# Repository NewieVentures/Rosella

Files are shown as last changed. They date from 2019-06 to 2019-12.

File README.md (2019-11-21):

# Rosella (code name Project Faraday)
### By NewieVentures

Remote control of LED strip lights via DMX over cellular.

## Hardware
### Artifacts
* FP1 - Motherboard
* FP2 - DMX expansion module
* FA1 - Assembled unit
* FA2 - Demonstration panel

## LED patterns
To update the pattern of an active device, the device ID and a valid access token is required:

`curl -v "https://api.particle.io/v1/devices/<DEVICE_ID>/<function>" -d access_token=<TOKEN> -d arg=<ARG>`

eg to set a green strobe at 1Hz:

`curl -v "https://api.particle.io/v1/devices/<your device ID here>/strobe" -d access_token=<your access token here> -d arg="1000,#00FF00"`

### Blink
Flash LEDs on and off. Duty cycle controls amount of time on vs off.
#### Arguments
`"<period (ms)>,<duty cycle (0-100)>,<colour-on>,<colour-off>"`

eg blink red 1s:

`POST /v1/devices/:deviceId/blink { "arg": "1000,50,#FF0000,#000000" }`

### Colour
Fixed colour on all leds
#### Arguments
`"<colour>"`

Eg all LEDS blue:

`POST /v1/devices/:deviceId/colour { "arg": "#0000FF" }`

### Gradient
Linear colour gradient
#### Arguments
`"<start-colour>,<end-colour>"`

eg gradient on all LEDS from red to green:

`POST /v1/devices/:deviceId/gradient { "arg": "#FF0000,#00FF00" }`

### Progress
Progress bar
#### Arguments
* Initial value: 0 - (# leds – 1)
* Final value: 1 - #leds
* Direction: 0 = first LED to last, 1 = last LED to first

`"<initial value>,<final value><increment (# leds)>,<increment delay (ms)>,<reset delay(ms)>,<direction>,<colour-on>,<colour-off>"`

eg Progress bar from 0 to 100 leds with 1s between increments, 5s pause at the final value
before repeating and starting from the first LED to the last, incrementing by 1 LED with
RED being on and black being off:

```
POST /v1/devices/:deviceId/progress
{ "arg": "0,100,1,1000,5000,0,#FF0000,#000000" }
```

### Snake
Block of LEDS moving along the strip.
#### Arguments
* Direction: 0 = first LED to last, 1 = last LED to first
`"<period (ms)>,<direction>,<length (# leds)>,<colour-on>,<colour-off>"`

eg Green block of 3 LEDS moving from first LED to last every 5s on a black background:

`POST /v1/devices/:deviceId/snake { "arg": "5000,0,3,#00FF00,#000000" }`

### Strobe
Flash LEDs
#### Arguments
`"<period (ms)>,<colour>"`

eg Blue flash at 1Hz

`POST /v1/devices/:deviceId/strobe { "arg": "1000,#0000FF" }`

## Firmware
The firmware is compiled using the particle cloud development tools (internet connection required).

### Setup
Install the particle CLI, see docs at
https://docs.particle.io/tutorials/developer-tools/cli/

### Compiling
To compile using the particle CLI:
`particle compile electron app --saveTo electron.bin`

### Flashing
To flash a binary to the module over USB, put it into programming mode then:
`particle flash --usb electron.bin`

### Unit tests
```
cd src
make tests && ./tests
```

### Structure
The firmware runs on a Particle Electron board, using their Device OS.  The major firmware modules are:
* cloudFunctions - functions registered with Particle's Device OS on boot and called via their cloud interface.
* LedStripDriver - generates colour values for each LED based on the pattern and settings.  The cloud functions change the pattern settings, while a timer in the RTOS calls the onTimerFired() method to process the new values.
* dmx - uses Serial1 to send the DMX packets (requires some low level override of the baud rate to send the break and mark-after-break at the start of the packet) and sends the NULL start code in each packet.

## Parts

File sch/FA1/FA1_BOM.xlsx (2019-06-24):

Refs | Description | Manufacturer | Order Number | Part Number | Supplier | Quantity | Price | Subtotal | Notes
D1 | LED PANEL INDICATOR RED 1.8V IP67 | E-Switch | EG5379-ND | PVL16FLS11 | Digikey | 1 | $16.49 | $16.49
D2 | LED PANEL INDICATOR BLUE 2.8V IP67 | E-Switch | EG5381-ND | PVL16FLS41 | Digikey | 1 | $16.49 | $16.49
J1 | PWR ENT RCPT IEC320-C14 PANEL QC | Qualtek | Q212-ND | 703W-00/04 | Digikey | 1 | $1.19 | $1.19
J2 | CONN SMA JACK STR 50 OHM SOLDER | Amphenol | ACX1183-ND | 132105 | Digikey | 1 | $11.94 | $11.94
J3 | TERM BLK HEADER 4POS GREEN | Phoenix Contact | 277-6689-ND | 1899155 | Digikey | 1 | $6.49 | $6.49
U1 | FP1 sub-assembly |  |  |  |  | 1 |  | $0.00
U2 | AC/DC CONVERTER 5V 5W | Mean Well | 1866-5411-ND | PS-05-5 | Digikey | 1 | $9.64 | $9.64 | Not required if using PSU on FP1
 | IP65 Sealed ABS enclosure 222x146x55mm | Multicomp | HB-6130 | MC001120 | Jaycar | 1 | $24.95 | $24.95
 | CONN HOUSING VH 2POS 3.96MM WHT | JST | 455-1183-ND | VHR-2N | Digikey | 3 | $0.17 | $0.51
 | CONN HOUSING VH 3POS 3.96MM WHT | JST | 455-1184-ND | VHR-3N | Digikey | 1 | $0.20 | $0.20
 | CONN TERM CRIMP VH/NV 18-22AWG | JST | 455-1133-1-ND | SVH-21T-P1.1 | Digikey | 9 | $0.16 | $1.44
 | Wire |  |  |  |  |  |  |  | Used for LEDs, IEC, SMA and DMX
 | ANT LTE BLADE SWIVEL DIPOLE SMA | Linx Technologies | ANT-LTE-WS-SMA-ND | ANT-LTE-WS-SMA | Digikey | 1 | $13.62 | $13.62
 | Screw M3 x 6mm Pan SS |  |  |  |  | 4 |  | $0.00
 | Washer Flat M3 SS |  |  |  |  | 4 |  | $0.00
 | Screw M3 x 10mm Pan SS |  |  |  |  | 4 |  | $0.00
 | Nut M3 SS |  |  |  |  | 4 |  | $0.00
 | Washer Spring M3 SS |  |  |  |  | 4 |  | $0.00
 | TERM BLOCK PLUG 4POS STR 5.08MM | Phoenix Contact | 277-5925-ND | 1780002 | Digikey | 1 | $8.88 | $8.88
 | CBL ASSY U.FL PLUG to cable 100mm | Hirose Electric Co | H125220-ND | U.FL-LP-066J1-A-(100) | Digikey | 1 | $8.02 | $8.02 | Can use cable from kit (de-solder from PCB antenna)
 |  |  |  |  |  |  | Total | $86.88

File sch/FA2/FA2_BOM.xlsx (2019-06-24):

Refs | Description | Manufacturer | Order Number | Part Number | Supplier | Quantity | Price | Subtotal | Notes
U1 | DMX-512 Decoder SPI output 5-24VDC | LTECH | LT-DMX-1809 | LT-DMX-1809 | Agoeu LED Express Store | 1 | $34.11 | $34.11
U2 | FA1 | Newie Ventures |  |  |  | 1 |  | $0.00
U3 | AC adapter 110-240VAC to 5V 3A DC |  | MP3480 |  | Jaycar | 1 | $24.95 | $24.95
U4, U5 | 5M RGB LED Strip - WS2812 60 Per Meter - White Strip - Weatherproof |  | CE04854 |  | Core Electronics | 0.4 | $69.00 | $27.60
 | Melamine panel |  |  |  |  | 1
 | Power board |  | MS4040 |  | Jaycar | 1 | $5.00 | $5.00
 | IEC cable |  | PS4106 |  |  | 1 | $8.95 | $8.95
 | Screws, wood
 |  |  |  |  |  |  | Total | $91.66

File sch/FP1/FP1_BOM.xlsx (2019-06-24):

Refs | Description | Manufacturer | Order Number | Part Number | Supplier | Quantity | Price | Subtotal | Notes
C1, C5 | CAP CER 1nF 450V C0G 0805 | TDK | 445-15536-1-ND | CGA4C4C0G2W102J060AA | Digikey | 2 | $0.51 | $1.02 | Optional if external 5VDC used
C2 | CAP CER 1UF 50V X7R 0805 | Samsung Electro-mechanics | 1276-6470-1-ND | CL21B105KBFNNNG | Digikey | 1 | $0.20 | $0.20
C3 | CAP ALUM 470UF 20% 10V RADIAL | Kemet | 399-6589-ND | ESH477M010AE3AA | Digikey | 1 | $0.36 | $0.36
C4 | CAP CER 0.1uF 630V X7R 1210 | Kemet | 399-13490-1-ND | C1210C104KBRAC7800 | Digikey | 1 | $0.69 | $0.69
C6 | CAP CER 10UF 10V 10% X5R 0805 | Samsung Electro-mechanics | 1276-2402-1-ND | CL21A106KPCLQNC | Digikey | 1 | $0.30 | $0.30
C7 | CAP CER 0.1UF 50V X7R 0805 | Murata | 490-8049-1-ND | GCM21BR71H104KA37K | Digikey | 1 | $0.33 | $0.33
D1 | TVS DIODE 7Vs 12Vc 600W | Littelfuse | SMBJ7.0ALFCT-ND | SMBJ7.0A | Digikey | 1 | $0.61 | $0.61
F1 | FUSE BOARD MNT 2A 250VAC 125VDC | Schurter | 486-1250-ND | 3403.0169.11 | Digikey | 1 | $0.93 | $0.93 | Optional if external 5VDC used
J1 | CONN HEADER VH TOP 3POS 3.96MM | JST | 455-1640-ND | B3P-VH(LF)(SN) | Digikey | 1 | $0.35 | $0.35 | Optional if external 5VDC used
J2, J4 | CONN HEADER FEMALE 9POS .1\" GOLD | Sullins Connector Solutions | S7042-ND | PPPC091LFBN-RC | Digikey | 4 | $0.97 | $3.88
J3, J5, J6 | CONN HEADER VH TOP 2POS 3.96MM | JST | 455-1639-ND | B2P-VH(LF)(SN) | Digikey | 3 | $0.27 | $0.81
L1 | IND 4.7uH 2A 72 mOHM SMD | Taiyo Yuden | 587-2407-1-ND | NRS5020T4R7MMGJ | Digikey | 1 | $0.49 | $0.49 | Optional if external 5VDC used
L2 | Common Mode Choke 10mH 2A 2 lines through hole | Schaffner | 817-2142-ND | RN143-2-02-10M | Digikey | 1 | $4.18 | $4.18 | Optional if external 5VDC used
PS1 | AC-DC 100-240VAC to 5VDC 2A and 12V 400mA | Mornsun | LHE15-20D0512-04 | LHE15-20D0512-04 | Mornsun | 1 |  | $0.00 | Optional if external 5VDC used
R1, R2 | RES SMD 4.7K OHM 5% 1/8W 0805 | Yageo | 311-4.7KARCT-ND | RC0805JR-074K7L | Digikey | 2 | $0.14 | $0.28
R3, R4 | RES SMD 220 OHM 5% 0.4W 0805 | Rohm | RHM220KCT-ND | ESR10EZPJ221 | Digikey | 2 | $0.14 | $0.28
RV1 | VARISTOR 470V 4.5KA DISC 14MM | Bourns | MOV-14D471K-ND | MOV-14D471K | Digikey | 1 | $0.68 | $0.68 | Optional if external 5VDC used
U1 | Particle Electron 3G Kit | Particle | CE04423 | Electron | Core Electronics | 1 | $135.00 | $135.00
J2, J4 | CONN HEADER FEMALE 4POS .1\" GOLD | Sullins Connector Solutions | S7037-ND | PPPC041LFBN-RC | Digikey | 4 | $0.68 | $2.72
 |  |  |  |  |  |  | Total | $153.11

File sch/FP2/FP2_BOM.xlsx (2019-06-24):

Refs | Description | Manufacturer | Order Number | Part Number | Supplier | Quantity | Price | Subtotal | Notes
C1 | CAP CER 10UF 10V X5R 0805 | Samsung Electro-mechanics | 1276-2402-1-ND | CL21A106KPCLQNC | Digikey | 1 | $0.30 | $0.30
C2 | CAP CER 0.1UF 50V X7R 0805 | Murata | 490-8049-1-ND | GCM21BR71H104KA37K | Digikey | 1 | $0.33 | $0.33
D1, D2 | TVS DIODE 43V 69.4V DO214AA | Littelfuse | SMBJ43CALFCT-ND | SMBJ43CA | Digikey | 2 | $0.84 | $1.68
J1 | TERMINAL BLOCK 5.08MM 3POS PCB | On Shore Technology | ED2903-ND | OSTYC032150 | Digikey | 1 | $1.55 | $1.55
J2 | CONN HEADER MALE 18POS .1\" | Amphenol FCI | 609-5513-ND | 68001-418HLF | Digikey | 1 | $0.87 | $0.87
R1, R5, R6 | RES SMD 10K OHM 1% 1/8W 0805 | Yageo | 311-10.0KCRCT-ND | RC0805FR-0710KL | Digikey | 3 | $0.14 | $0.42
R2, R4 | RES SMD 10 OHM 5% 0.4W 0805 | Rohm | RHM10KCT-ND | ESR10EZPJ100 | Digikey | 2 | $0.14 | $0.28
R3 | RES SMD 120 OHM 5% 0.4W 0805 | Rohm | RHM120KCT-ND | ESR10EZPJ121 | Digikey | 1 | $0.14 | $0.14
U1 | IC TXRX RS485 HALF DUPLEX 8SOIC | MaxLinear | 1016-1827-6-ND | SP485EEN-L/TR | Digikey | 1 | $1.46 | $1.46
 |  |  |  |  |  |  | Total | $7.03

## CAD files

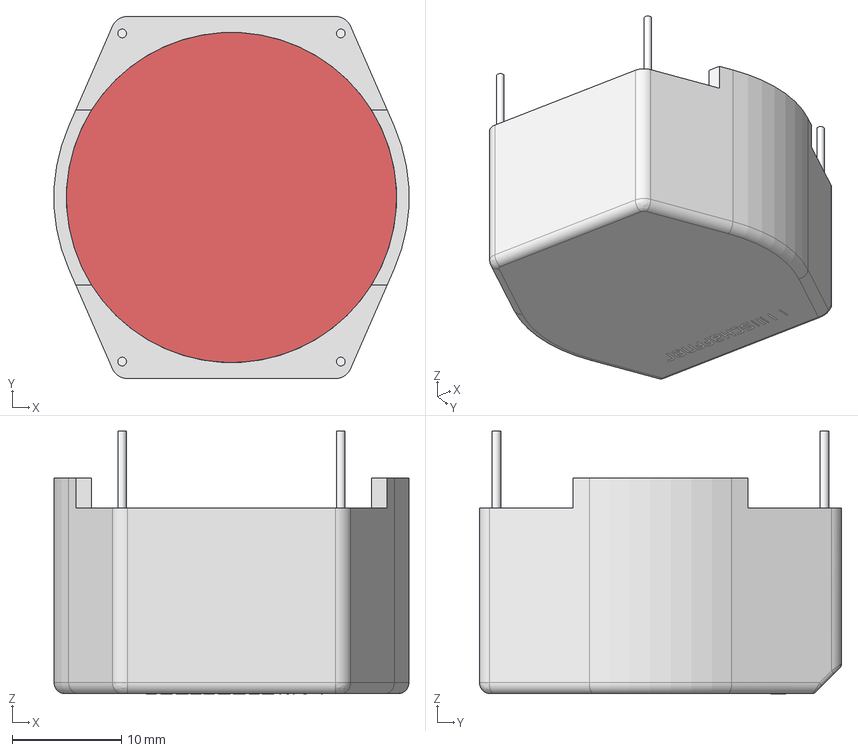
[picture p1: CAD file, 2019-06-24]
sch/3D files/RN143-x-02.stp
32.4 x 33.1 x 24.0 mm

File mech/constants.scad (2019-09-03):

$fn=400; // How many sections to use for circles

/************************************************************************
* Seeeduino board
************************************************************************/
SEEEDUINO_BRD_W = 53.4;
SEEEDUINO_BRD_L = 68.6;
SEEEDUINO_BRD_H = 1.2;
SEEEDUINO_HOLE_D = 3.2;

HDR_W = 2.5;
HDR_H = 9.1;
HDR_L_TL = 20.9;
HDR_L_BL = 26.0;
HDR_L_TR = 15.8;
HDR_L_BR = 20.9;

HDR_OFS_TOP = 2.6;

HOLE_OFS_X = SEEEDUINO_HOLE_D/2 + 1;
BOT_HOLE_OFS_Y = SEEEDUINO_HOLE_D/2 + 1;
MID_OUT_HOLE_OFS_Y = 16.9 - SEEEDUINO_HOLE_D/2;

MID_IN_HOLE_OFS_X = 6.6 + SEEEDUINO_HOLE_D/2;
MID_IN_HOLE_OFS_Y = 6.6 + SEEEDUINO_HOLE_D/2;

TOP_RIGHT_HOLE_OFS_X = SEEEDUINO_BRD_W - 6 - SEEEDUINO_HOLE_D/2;
TOP_LEFT_HOLE_OFS_X = SEEEDUINO_BRD_W - 37.2 - SEEEDUINO_HOLE_D/2;
TOP_HOLE_OFS_Y = SEEEDUINO_BRD_L - 1 - SEEEDUINO_HOLE_D/2;

BRD_HOLE_OFS_X_BL = SEEEDUINO_HOLE_D/2 + 1;
BRD_HOLE_OFS_X_BR = SEEEDUINO_BRD_W - BRD_HOLE_OFS_X_BL;
BRD_HOLE_OFS_X_TL = SEEEDUINO_BRD_W - 37.2 + SEEEDUINO_HOLE_D/2;
BRD_HOLE_OFS_X_TR = SEEEDUINO_BRD_W - 6 - SEEEDUINO_HOLE_D/2;

BRD_HOLE_OFS_Y_BL = SEEEDUINO_HOLE_D/2 + 1;
BRD_HOLE_OFS_Y_BR = BRD_HOLE_OFS_Y_BL;
BRD_HOLE_OFS_Y_TL = SEEEDUINO_BRD_L - 1 - SEEEDUINO_HOLE_D/2;
BRD_HOLE_OFS_Y_TR = BRD_HOLE_OFS_Y_TL;

BRD_MOUNT_HOLE_D = 3.0;

/************************************************************************
* Mount plate
************************************************************************/
MOUNT_PLATE_D = 71;
MOUNT_PLATE_H = 2.9;
MOUNT_HOLE_D = 4.2;
BRD_POST_D = 6.5;
BRD_POST_LEN = 10;
BRD_POST_ANG = 60;
BRD_POST_H = 5;
BRD_SCREW_POST_H = 3;
SCREW_HEAD_D = 7.6;
SCREW_HEAD_H = 2.7;

MNT_HOLE_TO_HOLE = 54.2; // center to center
MNT_HOLE_EDGE_OFS = 2.6; // offset from disc edge
MNT_HOLE_ANGLE = 60;

STR_REL_D = 6;
STR_REL_H = 5;
STR_REL_HOLE_D = 3;

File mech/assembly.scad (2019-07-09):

include <constants.scad>
use <button_mount_plate.scad>
use <seeeduino_lorawan_shield.scad>

mount_plate();

translate([-SEEEDUINO_BRD_W/2, -SEEEDUINO_BRD_L/2, MOUNT_PLATE_H + BRD_POST_H]) seeeduino_lorawan_shield();

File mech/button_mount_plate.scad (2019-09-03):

include <constants.scad>

MNT_TOP_Y = MOUNT_PLATE_D/2 - MNT_HOLE_EDGE_OFS - MOUNT_HOLE_D/2;

TERM_BLOCK_SIZE = 36;

SHOW_TERM_BLOCK = false;

module mount_hole() {
    translate([0, 0, MOUNT_PLATE_H - SCREW_HEAD_H + 0.001]) 
      cylinder(d1=MOUNT_HOLE_D, d2=SCREW_HEAD_D, h=SCREW_HEAD_H);
    cylinder(d=MOUNT_HOLE_D, h=MOUNT_PLATE_H*3, center=true);
}

module mounting_post(l, x_ofs, y_ofs, angle) {
    translate([-(SEEEDUINO_BRD_W/2 - x_ofs), 
                   -(SEEEDUINO_BRD_L/2 - y_ofs), 
                   MOUNT_PLATE_H+0.001]) {
      difference() {
        union() {
            hull() {
              cylinder(d=BRD_POST_D, h=BRD_POST_H);
              translate([l*cos(angle), l*sin(angle)]) cylinder(d=BRD_POST_D, h=BRD_POST_H);
            }
        translate([0, 0, BRD_POST_H]) cylinder(d=BRD_POST_D, h=BRD_SCREW_POST_H);
        }
        cylinder(d=BRD_MOUNT_HOLE_D, 3*(BRD_POST_H + BRD_SCREW_POST_H), center=true);
      }
        
        
    }
}

module mount_plate() {
    difference() {
        color("grey") cylinder(d=MOUNT_PLATE_D, h=MOUNT_PLATE_H);
        
        // mount hole top
        translate([0, MNT_TOP_Y, 0]) mount_hole();
        
        // mount hole left
        translate([-(MNT_HOLE_TO_HOLE*sin(MNT_HOLE_ANGLE/2)), MNT_TOP_Y - MNT_HOLE_TO_HOLE*cos(MNT_HOLE_ANGLE/2), 0]) mount_hole();
        
        // mount hole right
        translate([(MNT_HOLE_TO_HOLE*sin(MNT_HOLE_ANGLE/2)), MNT_TOP_Y - MNT_HOLE_TO_HOLE*cos(MNT_HOLE_ANGLE/2), 0]) mount_hole();
    }
    
    // bottom left
    mounting_post(BRD_POST_LEN, BRD_HOLE_OFS_X_BL, BRD_HOLE_OFS_Y_BL, angle=52.5);

    // bottom right
    mounting_post(0.88*BRD_POST_LEN, BRD_HOLE_OFS_X_BR, BRD_HOLE_OFS_Y_BR, angle=80);

    // top left
    mounting_post(BRD_POST_LEN, BRD_HOLE_OFS_X_TL, BRD_HOLE_OFS_Y_TL, angle=-90);

    // top right
    mounting_post(BRD_POST_LEN, BRD_HOLE_OFS_X_TR, BRD_HOLE_OFS_Y_TR, angle=-120);
}

rotate([0, 0, 120]) mount_plate();

if (SHOW_TERM_BLOCK) {
    translate([0, -60, 0]) color("green") cube([TERM_BLOCK_SIZE, TERM_BLOCK_SIZE, 10]);
}

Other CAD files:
mech/seeeduino_lorawan_shield.scad

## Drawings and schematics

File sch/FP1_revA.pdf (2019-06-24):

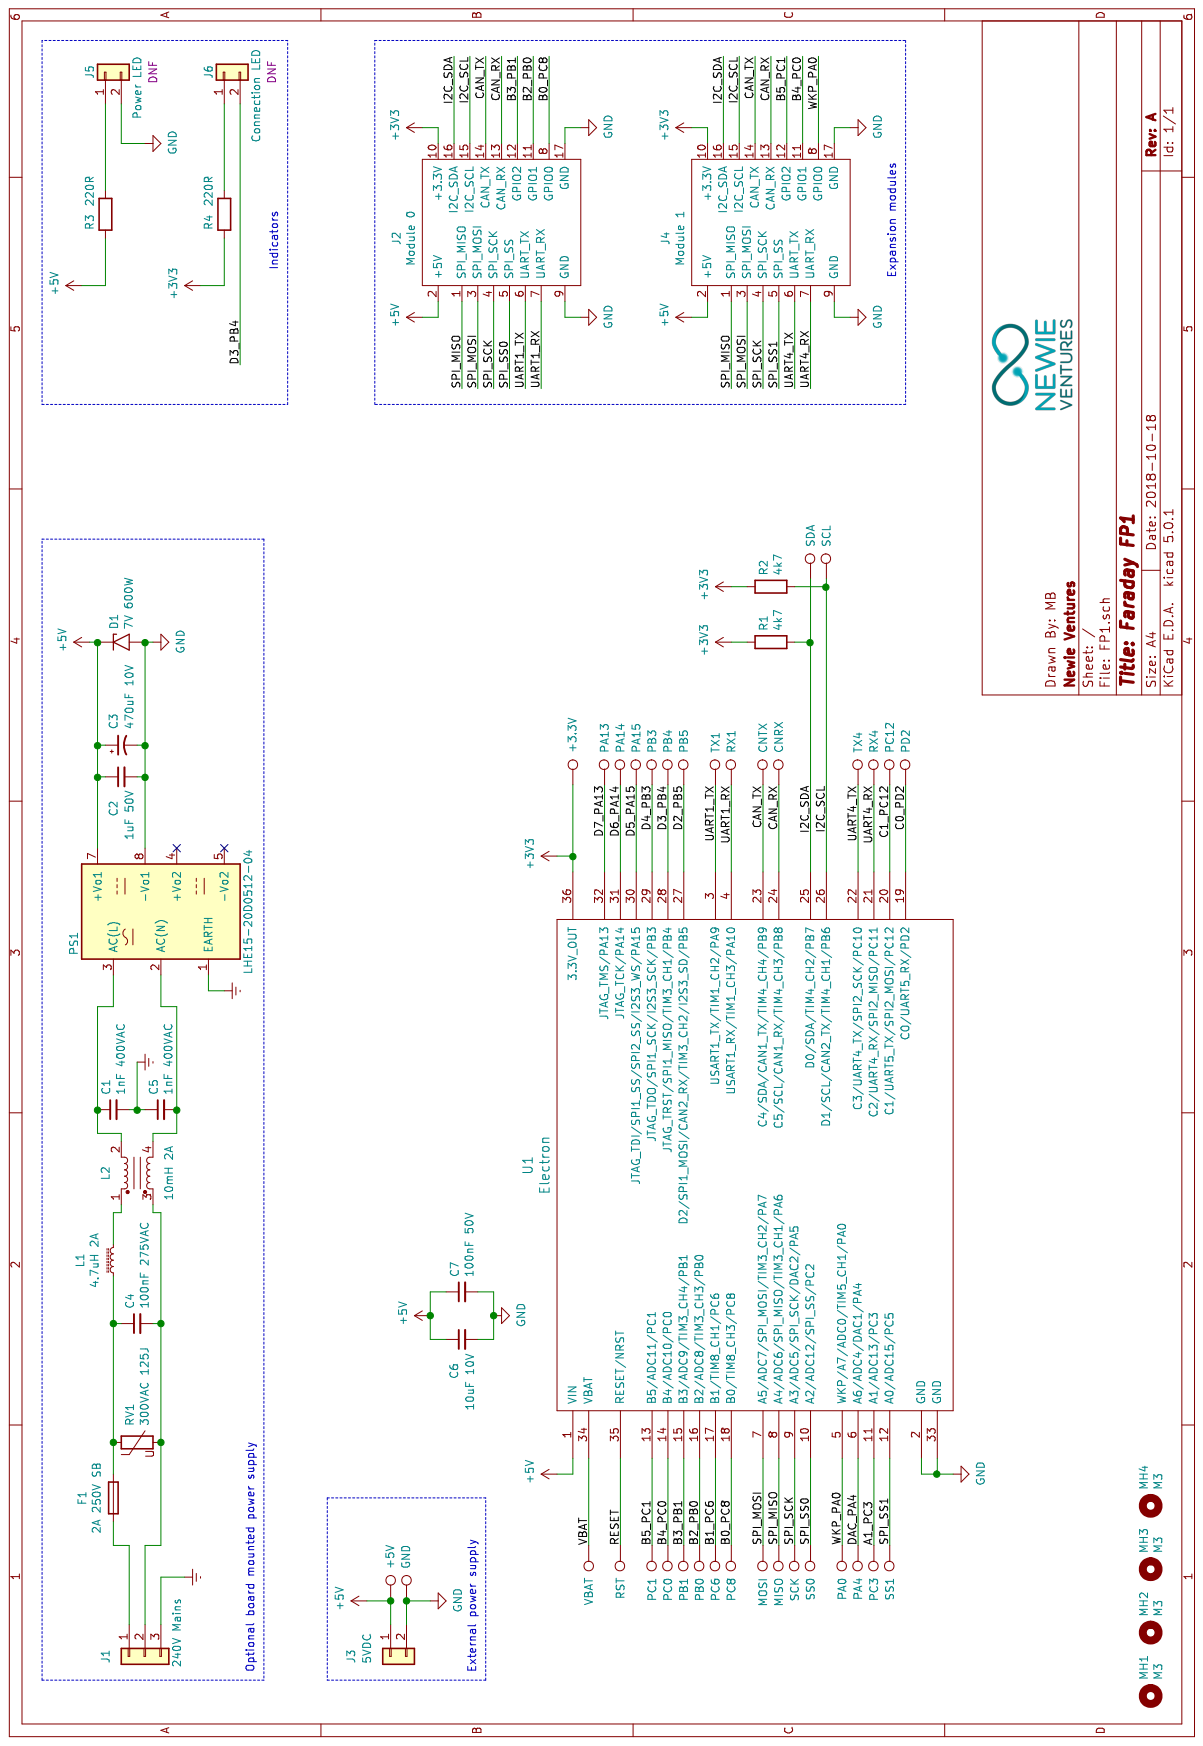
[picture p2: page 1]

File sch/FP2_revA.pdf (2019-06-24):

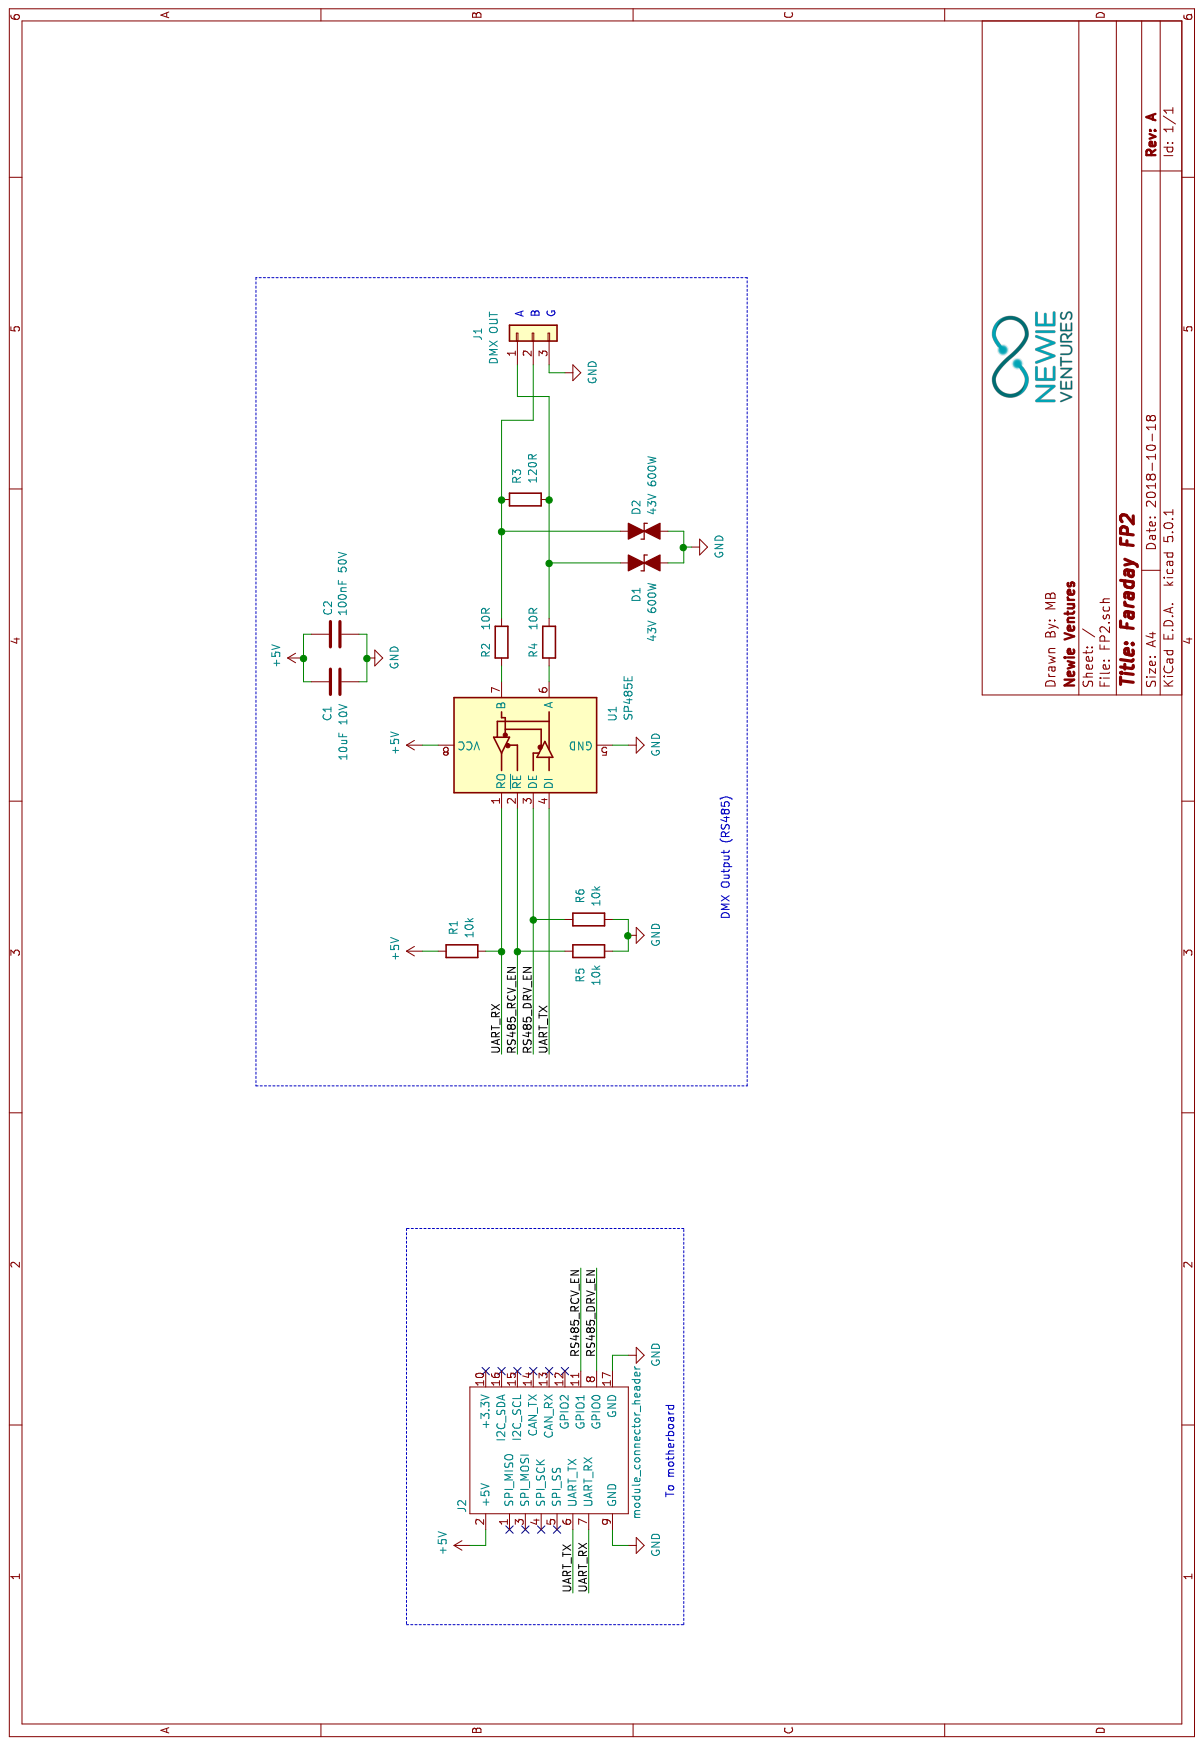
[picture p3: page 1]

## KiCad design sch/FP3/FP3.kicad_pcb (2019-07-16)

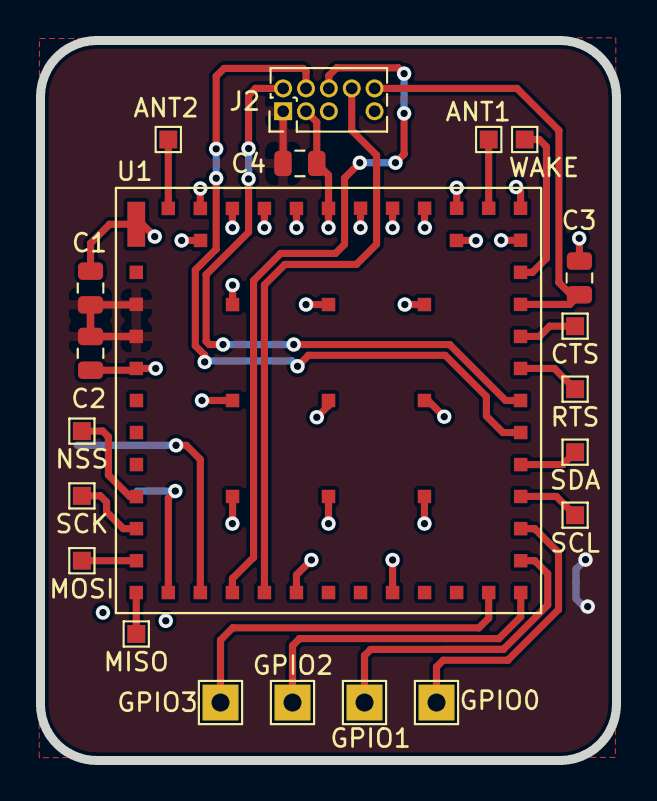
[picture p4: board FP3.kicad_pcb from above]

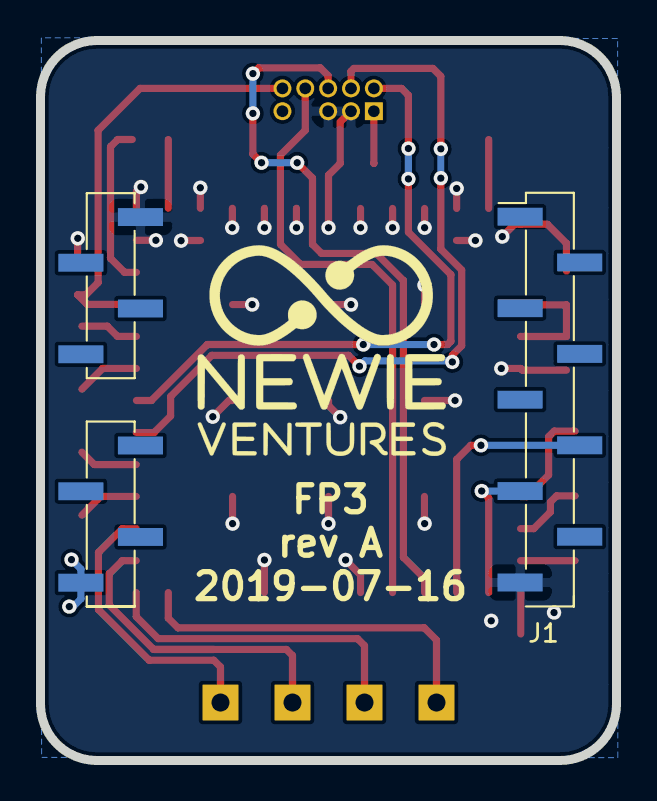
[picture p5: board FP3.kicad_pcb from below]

Board: 2 copper layers, 32.0 x 40.0 mm, 23 parts (2 on the bottom side), 24 nets.

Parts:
C1: 10uF 10V; R_0805_2012Metric
C2, C3, C4: 100nF 50V; R_0805_2012Metric
G1: Logo-NewieVentures-75px; logo_14.2x12.1mm
J1: module_connector_header; Faraday_module_smt_hdr
J2: MXDOT_Prog_Header_Keyed; Header_MDOT_PROG_2x05_Pitch1.27mm
TP1: GPIO3; TestPoint_THTPad_2.0x2.0mm_Drill1.0mm
TP2: GPIO2; TestPoint_THTPad_2.0x2.0mm_Drill1.0mm
TP3: GPIO1; TestPoint_THTPad_2.0x2.0mm_Drill1.0mm
TP4: GPIO0; TestPoint_THTPad_2.0x2.0mm_Drill1.0mm
TP5: WAKE; TestPoint_Pad_1.0x1.0mm
TP6: NSS; TestPoint_Pad_1.0x1.0mm
TP7: SCK; TestPoint_Pad_1.0x1.0mm
TP8: MOSI; TestPoint_Pad_1.0x1.0mm
TP9: CTS; TestPoint_Pad_1.0x1.0mm
TP10: MISO; TestPoint_Pad_1.0x1.0mm
TP11: RTS; TestPoint_Pad_1.0x1.0mm
TP12: SCL; TestPoint_Pad_1.0x1.0mm
TP13: SDA; TestPoint_Pad_1.0x1.0mm
TP14: ANT1; TestPoint_Pad_1.0x1.0mm
TP15: ANT2; TestPoint_Pad_1.0x1.0mm
U1: MTXDOT-AU1-A01-100; MTXDOT-AS1-A00-1

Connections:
+3V3: C1.1, C2.1, C4.1, J1.10, J2.1, U1.3, U1.4
/MBED_RX: J2.6, U1.15
/MBED_TX: J2.8, U1.16
/NRESET: C3.1, J2.10, U1.33
/SWCLK: J2.4, U1.29
/SWDIO: J2.2, U1.30
/UART_RX: J1.7, U1.13
/UART_TX: J1.6, U1.14
GND: C1.2, C2.2, C3.2, C4.2, J1.9, J1.17, J2.3, J2.5, U1.1, U1.5, U1.17, U1.20, U1.35, U1.36, U1.38, U1.39, U1.40, U1.41, U1.42, U1.43, U1.44, U1.45, U1.46, U1.48, U1.49, U1.50, U1.51, U1.52, U1.53, U1.54, U1.55, U1.56, U1.57, U1.58
unnamed: TP1.1, U1.23
unnamed: TP2.1, U1.24
unnamed: TP3.1, U1.25
unnamed: TP4.1, U1.26
unnamed: TP5.1, U1.34
unnamed: TP6.1, U1.9
unnamed: TP7.1, U1.10
unnamed: TP8.1, U1.11
unnamed: TP9.1, U1.32
unnamed: TP10.1, U1.12
unnamed: TP11.1, U1.31
unnamed: TP12.1, U1.27
unnamed: TP13.1, U1.28
unnamed: TP14.1, U1.37
unnamed: TP15.1, U1.47

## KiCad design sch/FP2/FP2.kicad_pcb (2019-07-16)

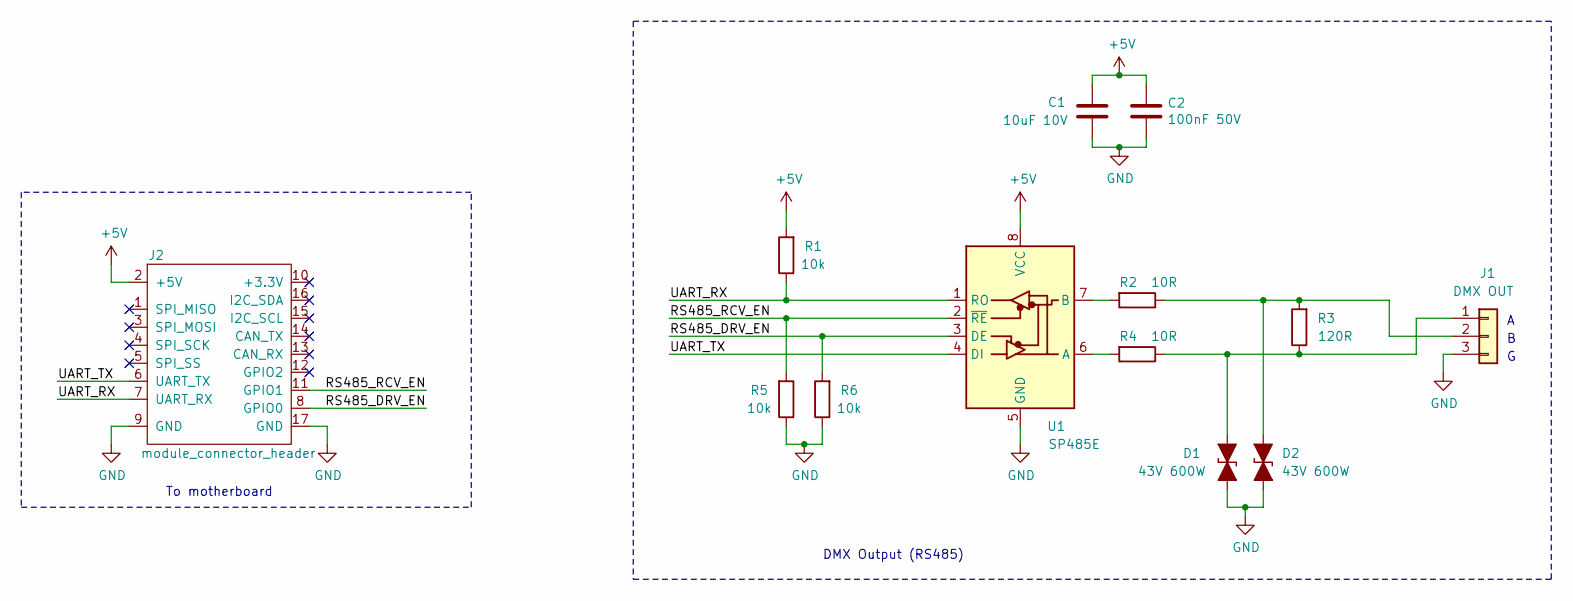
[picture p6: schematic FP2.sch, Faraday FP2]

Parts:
C1: 10uF 10V; R_0805_2012Metric; Part Number CL21A106KPCLQNC
C2: 100nF 50V; R_0805_2012Metric; Part Number GCM21BR71H104KA37K
D1, D2: 43V 600W; D_SMB_NP; Part Number SMBJ43CA
J1: DMX OUT; TerminalBlock_Phoenix_MKDS-1,5-3-5.08_1x03_P5.08mm_Horizont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; Part Number OSTYC032150
J2: module_connector_header; Faraday_module; Part Number 68001-418HLF
R1, R5, R6: 10k; R_0805_2012Metric; Part Number RC0805FR-0710KL
R2, R4: 10R; R_0805_2012Metric; Part Number ESR10EZPJ100
R3: 120R; R_0805_2012Metric; Part Number ESR10EZPJ121
U1: SP485E; SOIC-8_3.9x4.9mm_P1.27mm; Part Number SP485EEN-L/TR

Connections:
+5V: C1.1, C2.1, J2.2 (+5V), R1.2, U1.8 (VCC)
/RS485_DRV_EN: J2.8 (GPIO0), R6.2, U1.3 (DE)
/RS485_RCV_EN: J2.11 (GPIO1), R5.2, U1.2 (~RE)
/UART_RX: J2.7 (UART_RX), R1.1, U1.1 (RO)
/UART_TX: J2.6 (UART_TX), U1.4 (DI)
GND: C1.2, C2.2, D1.2 (A2), D2.2 (A2), J1.3, J2.9 (GND), J2.17 (GND), R5.1, R6.1, U1.5 (GND)
unnamed: D1.1 (A1), J1.1, R3.1, R4.1
unnamed: D2.1 (A1), J1.2, R2.1, R3.2
unnamed: R2.2, U1.7 (B)
unnamed: R4.2, U1.6 (A)

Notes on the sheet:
To motherboard
DMX Output (RS485)

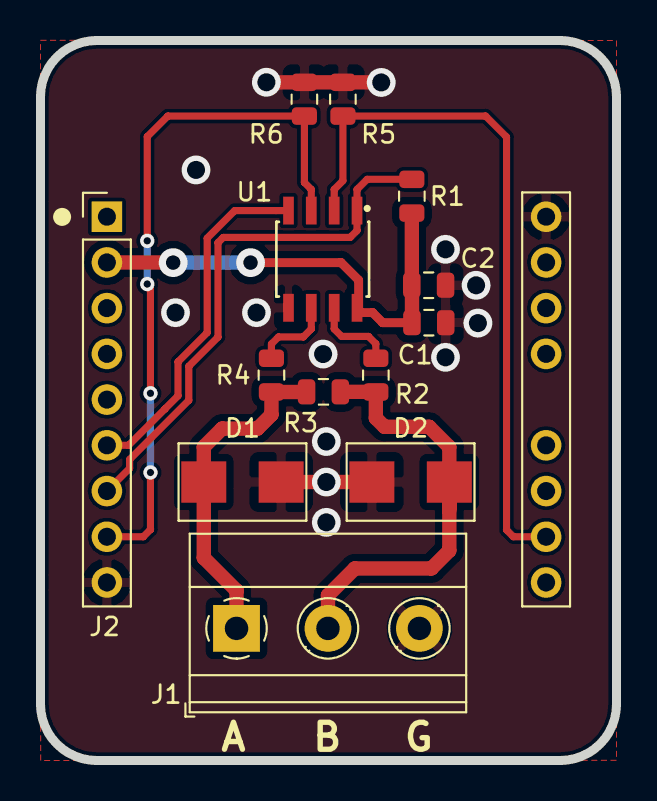
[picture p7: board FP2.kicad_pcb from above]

Board: 2 copper layers, 32.0 x 40.0 mm, 13 parts (0 on the bottom side), 10 nets.

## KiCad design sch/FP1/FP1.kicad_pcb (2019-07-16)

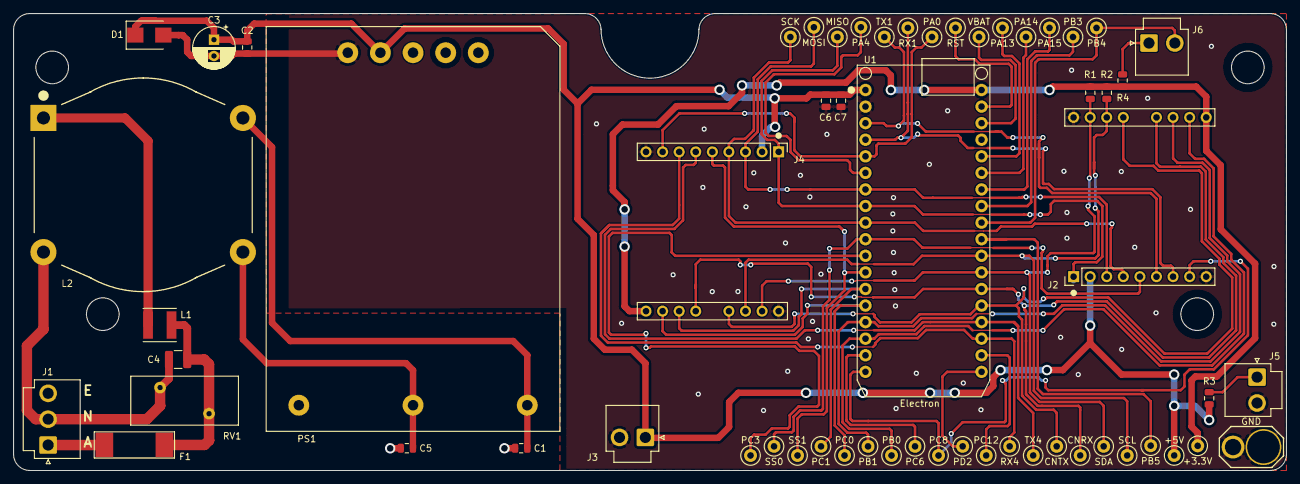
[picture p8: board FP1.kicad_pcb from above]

Board: 2 copper layers, 195.0 x 70.0 mm, 63 parts (0 on the bottom side), 44 nets.

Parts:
C1, C5: 1nF 400VAC; C_0805_2012Metric
C2: 1uF 50V; C_0805_2012Metric
C3: 470uF 10V; CP_Radial_D6.3mm_P2.50mm
C4: 100nF 275VAC; C_1210_3225Metric
C6: 10uF 10V; C_0805_2012Metric
C7: 100nF 50V; C_0805_2012Metric
D1: 7V 600W; D_SMB
F1: 2A 250V SB; Fuse_SMD_10W_3H
J1: 240V Mains; JST_VH_B3P-VH-B_1x03_P3.96mm_Vertical
J2: Module 0; Faraday_module
J3: 5VDC; JST_VH_B2P-VH_1x02_P3.96mm_Vertical
J4: Module 1; Faraday_module
J5: Power LED; JST_VH_B2P-VH_1x02_P3.96mm_Vertical
J6: Connection LED; JST_VH_B2P-VH_1x02_P3.96mm_Vertical
L1: 4.7uH 2A; L_Taiyo-Yuden_NR-50xx
L2: 10mH 2A; Choke_Schaffner_RN143-02-33.1x32.5mm
MH1, MH2, MH3, MH4: M3; MountingHole_3.5mm
PS1: LHE15-20D0512-04; LHE15-20
R1, R2: 4k7; R_0805_2012Metric
R3, R4: 220R; R_0805_2012Metric
RV1: 300VAC 125J; RV_Disc_D16.5mm_W7.5mm_P7.5mm
TP1: VBAT; TestPoint_Loop_D2.50mm_Drill1.0mm
TP2: PA13; TestPoint_Loop_D2.50mm_Drill1.0mm
TP3: RST; TestPoint_Loop_D2.50mm_Drill1.0mm
TP4: PA14; TestPoint_Loop_D2.50mm_Drill1.0mm
TP5: PA15; TestPoint_Loop_D2.50mm_Drill1.0mm
TP6: PC1; TestPoint_Loop_D2.50mm_Drill1.0mm
TP7: PB3; TestPoint_Loop_D2.50mm_Drill1.0mm
TP8: PC0; TestPoint_Loop_D2.50mm_Drill1.0mm
TP9: PB4; TestPoint_Loop_D2.50mm_Drill1.0mm
TP10: PB1; TestPoint_Loop_D2.50mm_Drill1.0mm
TP11: PB5; TestPoint_Loop_D2.50mm_Drill1.0mm
TP12: PB0; TestPoint_Loop_D2.50mm_Drill1.0mm
TP13: PC6; TestPoint_Loop_D2.50mm_Drill1.0mm
TP14: TX1; TestPoint_Loop_D2.50mm_Drill1.0mm
TP15: PC8; TestPoint_Loop_D2.50mm_Drill1.0mm
TP16: RX1; TestPoint_Loop_D2.50mm_Drill1.0mm
TP17: MOSI; TestPoint_Loop_D2.50mm_Drill1.0mm
TP18: CNTX; TestPoint_Loop_D2.50mm_Drill1.0mm
TP19: MISO; TestPoint_Loop_D2.50mm_Drill1.0mm
TP20: CNRX; TestPoint_Loop_D2.50mm_Drill1.0mm
TP21: SCK; TestPoint_Loop_D2.50mm_Drill1.0mm
TP22: SS0; TestPoint_Loop_D2.50mm_Drill1.0mm
TP23: SDA; TestPoint_Loop_D2.50mm_Drill1.0mm
TP24: SCL; TestPoint_Loop_D2.50mm_Drill1.0mm
TP25: PA0; TestPoint_Loop_D2.50mm_Drill1.0mm
TP26: PA4; TestPoint_Loop_D2.50mm_Drill1.0mm
TP27: TX4; TestPoint_Loop_D2.50mm_Drill1.0mm
TP28: PC3; TestPoint_Loop_D2.50mm_Drill1.0mm
TP29: RX4; TestPoint_Loop_D2.50mm_Drill1.0mm
TP30: SS1; TestPoint_Loop_D2.50mm_Drill1.0mm
TP31: PC12; TestPoint_Loop_D2.50mm_Drill1.0mm
TP32: PD2; TestPoint_Loop_D2.50mm_Drill1.0mm
TP33: +5V; TestPoint_Loop_D2.50mm_Drill1.0mm
TP34: GND; Test_Point_Alligator_Clip_And_Probe
TP35: +3.3V; TestPoint_Loop_D2.50mm_Drill1.0mm
U1: Electron; PARTICLE_ELECTRON

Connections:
+3V3: J2.10, J4.10, R1.1, R2.1, R4.2, TP35.1, U1.36
+5V: C2.1, C3.1, C6.1, C7.1, D1.1, J2.2, J3.1, J4.2, PS1.7, R3.2, TP33.1, U1.1
/A1_PC3: TP28.1, U1.11
/B0_PC8: J2.8, TP15.1, U1.18
/B1_PC6: TP13.1, U1.17
/B2_PB0: J2.11, TP12.1, U1.16
/B3_PB1: J2.12, TP10.1, U1.15
/B4_PC0: J4.11, TP8.1, U1.14
/B5_PC1: J4.12, TP6.1, U1.13
/C0_PD2: TP32.1, U1.19
/C1_PC12: TP31.1, U1.20
/CAN_RX: J2.13, J4.13, TP20.1, U1.24
/CAN_TX: J2.14, J4.14, TP18.1, U1.23
/D2_PB5: TP11.1, U1.27
/D3_PB4: J6.2, TP9.1, U1.28
/D4_PB3: TP7.1, U1.29
/D5_PA15: TP5.1, U1.30
/D6_PA14: TP4.1, U1.31
/D7_PA13: TP2.1, U1.32
/DAC_PA4: TP26.1, U1.6
/I2C_SCL: J2.15, J4.15, R2.2, TP24.1, U1.26
/I2C_SDA: J2.16, J4.16, R1.2, TP23.1, U1.25
/RESET: TP3.1, U1.35
/SPI_MISO: J2.1, J4.1, TP19.1, U1.8
/SPI_MOSI: J2.3, J4.3, TP17.1, U1.7
/SPI_SCK: J2.4, J4.4, TP21.1, U1.9
/SPI_SS0: J2.5, TP22.1, U1.10
/SPI_SS1: J4.5, TP30.1, U1.12
/UART1_RX: J2.7, TP16.1, U1.4
/UART1_TX: J2.6, TP14.1, U1.3
/UART4_RX: J4.7, TP29.1, U1.21
/UART4_TX: J4.6, TP27.1, U1.22
/VBAT: TP1.1, U1.34
/WKP_PA0: J4.8, TP25.1, U1.5
Earth: C1.2, C5.1, J1.3, PS1.1
GND: C2.2, C3.2, C6.2, C7.2, D1.2, J2.9, J2.17, J3.2, J4.9, J4.17, J5.2, PS1.8, TP34.1, U1.2, U1.33
unnamed: C1.1, L2.2, PS1.3
unnamed: C4.1, F1.1, L1.1, RV1.1
unnamed: C4.2, J1.2, L2.3, RV1.2
unnamed: C5.2, L2.4, PS1.2
unnamed: F1.2, J1.1
unnamed: J5.1, R3.1
unnamed: J6.1, R4.1
unnamed: L1.2, L2.1

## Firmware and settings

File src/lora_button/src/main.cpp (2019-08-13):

#include "dot_util.h"
#include "RadioEvent.h"

/////////////////////////////////////////////////////////////////////////////
// -------------------- DOT LIBRARY REQUIRED ------------------------------//
// * Because these example programs can be used for both mDot and xDot     //
//     devices, the LoRa stack is not included. The libmDot library should //
//     be imported if building for mDot devices. The libxDot library       //
//     should be imported if building for xDot devices.                    //
// * https://developer.mbed.org/teams/MultiTech/code/libmDot-dev-mbed5/    //
// * https://developer.mbed.org/teams/MultiTech/code/libmDot-mbed5/        //
// * https://developer.mbed.org/teams/MultiTech/code/libxDot-dev-mbed5/    //
// * https://developer.mbed.org/teams/MultiTech/code/libxDot-mbed5/        //
/////////////////////////////////////////////////////////////////////////////

/////////////////////////////////////////////////////////////
// * these options must match between the two devices in   //
//   order for communication to be successful
/////////////////////////////////////////////////////////////

#define CMD_BUTTON "Button"

#define BUTTON_VALUE_ON    0
#define BUTTON_VALUE_OFF   1
#define GPIO_ON_COUNT_MAX  1

static uint8_t network_address[] = { 0x00, 0x00, 0x00, 0x00 };
static uint8_t network_session_key[] = { 0x00, 0x00, 0x00, 0x00, 0x00, 0x00, 0x00, 0x00, 0x00, 0x00, 0x00, 0x00, 0x00, 0x00, 0x00, 0x00 };
static uint8_t data_session_key[] = { 0x00, 0x00, 0x00, 0x00, 0x00, 0x00, 0x00, 0x00, 0x00, 0x00, 0x00, 0x00, 0x00, 0x00, 0x00, 0x00 };

DigitalIn triggerGpio(PB_1);

mDot* dot = NULL;
lora::ChannelPlan* plan = NULL;

Serial pc(USBTX, USBRX);

/**********************************************************
 * Filter the given value to output BUTTON_VALUE_ON for a 
 * maximum time of GPIO_ON_COUNT_MAX * LOOP_DELAY per 
 * off -> on transition of the pin.
 * 
 * Input:   value to filter
 * Returns: filtered value
 *********************************************************/
int filterGpioValue(int value) {
  static int prevValue = BUTTON_VALUE_OFF;
  static int counter = 0;
  static int output = BUTTON_VALUE_OFF;

  if (prevValue == BUTTON_VALUE_OFF and value == BUTTON_VALUE_ON) {
    output = BUTTON_VALUE_ON;
    counter = 0;
  }

  if (counter >= GPIO_ON_COUNT_MAX) {
    output = BUTTON_VALUE_OFF;
  } else {
    ++counter;
  }

  prevValue = value;

  return output;
}

int main() {
    // Custom event handler for automatically displaying RX data
    RadioEvent events;
    uint32_t tx_frequency;
    uint8_t tx_datarate;
    uint8_t tx_power;
    uint8_t frequency_band;
    
    triggerGpio.mode(PullUp);

    pc.baud(115200);

    mts::MTSLog::setLogLevel(mts::MTSLog::TRACE_LEVEL);
    
#if CHANNEL_PLAN == CP_US915
    plan = new lora::ChannelPlan_US915();
#elif CHANNEL_PLAN == CP_AU915
    plan = new lora::ChannelPlan_AU915();
#elif CHANNEL_PLAN == CP_EU868
    plan = new lora::ChannelPlan_EU868();
#elif CHANNEL_PLAN == CP_KR920
    plan = new lora::ChannelPlan_KR920();
#elif CHANNEL_PLAN == CP_AS923
    plan = new lora::ChannelPlan_AS923();
#elif CHANNEL_PLAN == CP_AS923_JAPAN
    plan = new lora::ChannelPlan_AS923_Japan();
#elif CHANNEL_PLAN == CP_IN865
    plan = new lora::ChannelPlan_IN865();
#endif
    assert(plan);

    dot = mDot::getInstance(plan);
    assert(dot);

    logInfo("mbed-os library version: %d.%d.%d", MBED_MAJOR_VERSION, MBED_MINOR_VERSION, MBED_PATCH_VERSION);

    // start from a well-known state
    logInfo("defaulting Dot configuration");
    dot->resetConfig();

    // make sure library logging is turned on
    dot->setLogLevel(mts::MTSLog::INFO_LEVEL);

    // attach the custom events handler
    dot->setEvents(&events);

    // update configuration if necessary
    if (dot->getJoinMode() != mDot::PEER_TO_PEER) {
        logInfo("changing network join mode to PEER_TO_PEER");
        if (dot->setJoinMode(mDot::PEER_TO_PEER) != mDot::MDOT_OK) {
            logError("failed to set network join mode to PEER_TO_PEER");
        }
    }
    frequency_band = dot->getFrequencyBand();
    switch (frequency_band) {
        case lora::ChannelPlan::EU868_OLD:
        case lora::ChannelPlan::EU868:
            // 250kHz channels achieve higher throughput
            // DR_6 : SF7 @ 250kHz
            // DR_0 - DR_5 (125kHz channels) available but much slower
            tx_frequency = 869850000;
            tx_datarate = lora::DR_6;
            // the 869850000 frequency is 100% duty cycle if the total power is under 7 dBm - tx power 4 + antenna gain 3 = 7
            tx_power = 4;
            break;

        case lora::ChannelPlan::US915_OLD:
        case lora::ChannelPlan::US915:
        case lora::ChannelPlan::AU915_OLD:
        case lora::ChannelPlan::AU915:
            // 500kHz channels achieve highest throughput
            // DR_8 : SF12 @ 500kHz
            // DR_9 : SF11 @ 500kHz
            // DR_10 : SF10 @ 500kHz
            // DR_11 : SF9 @ 500kHz
            // DR_12 : SF8 @ 500kHz
            // DR_13 : SF7 @ 500kHz
            // DR_0 - DR_3 (125kHz channels) available but much slower
            tx_frequency = 915500000;
            tx_datarate = lora::DR_13;
            // 915 bands have no duty cycle restrictions, set tx power to max
            tx_power = 20;
            break;

        case lora::ChannelPlan::AS923:
        case lora::ChannelPlan::AS923_JAPAN:
            // 250kHz channels achieve higher throughput
            // DR_6 : SF7 @ 250kHz
            // DR_0 - DR_5 (125kHz channels) available but much slower
            tx_frequency = 924800000;
            tx_datarate = lora::DR_6;
            tx_power = 16;
            break;

        case lora::ChannelPlan::KR920:
            // DR_5 : SF7 @ 125kHz
            tx_frequency = 922700000;
            tx_datarate = lora::DR_5;
            tx_power = 14;
            break;

        default:
            while (true) {
                logFatal("no known channel plan in use - extra configuration is needed!");
                wait(5);
            }
            break;
    }
    // in PEER_TO_PEER mode there is no join request/response transaction
    // as long as both Dots are configured correctly, they should be able to communicate
    update_peer_to_peer_config(network_address, network_session_key, data_session_key, tx_frequency, tx_datarate, tx_power);
 
    // save changes to configuration
    logInfo("saving configuration");
    if (!dot->saveConfig()) {
        logError("failed to save configuration");
    }

    // display configuration
    display_config();

    logInfo("Waiting for input");

    while (true) {
        // join network if not joined
        if (!dot->getNetworkJoinStatus()) {
            join_network();
        }
        
        if (filterGpioValue(triggerGpio.read()) == BUTTON_VALUE_ON) {
            logInfo("Sending command");
            send_data(CMD_BUTTON, (uint8_t)sizeof(CMD_BUTTON));
        }

        // the Dot can't sleep in PEER_TO_PEER mode
        // it must be waiting for data from the other Dot
        wait(0.1);
    }
    
    return 0;
}

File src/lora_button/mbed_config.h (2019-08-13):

/*
 * mbed SDK
 * Copyright (c) 2017 ARM Limited
 *
 * Licensed under the Apache License, Version 2.0 (the "License");
 * you may not use this file except in compliance with the License.
 * You may obtain a copy of the License at
 *
 * http://www.apache.org/licenses/LICENSE-2.0
 *
 * Unless required by applicable law or agreed to in writing, software
 * distributed under the License is distributed on an "AS IS" BASIS,
 * WITHOUT WARRANTIES OR CONDITIONS OF ANY KIND, either express or implied.
 * See the License for the specific language governing permissions and
 * limitations under the License.
 */

// Automatically generated configuration file.
// DO NOT EDIT, content will be overwritten.

#ifndef __MBED_CONFIG_DATA__
#define __MBED_CONFIG_DATA__

// Configuration parameters
#define KVSTORE_ENABLED                                                       1                                                                                                // set by library:kvstore
#define LPTICKER_DELAY_TICKS                                                  1                                                                                                // set by target:FAMILY_STM32
#define MBED_CONF_APP_MAIN_STACK_SIZE                                         4096                                                                                             // set by library:mdot-library
#define MBED_CONF_APP_THREAD_STACK_SIZE                                       2048                                                                                             // set by library:mdot-library
#define MBED_CONF_ATMEL_RF_ASSUME_SPACED_SPI                                  1                                                                                                // set by library:atmel-rf[STM]
#define MBED_CONF_ATMEL_RF_FULL_SPI_SPEED                                     7500000                                                                                          // set by library:atmel-rf
#define MBED_CONF_ATMEL_RF_FULL_SPI_SPEED_BYTE_SPACING                        250                                                                                              // set by library:atmel-rf
#define MBED_CONF_ATMEL_RF_IRQ_THREAD_STACK_SIZE                              1024                                                                                             // set by library:atmel-rf
#define MBED_CONF_ATMEL_RF_LOW_SPI_SPEED                                      3750000                                                                                          // set by library:atmel-rf
#define MBED_CONF_ATMEL_RF_PROVIDE_DEFAULT                                    0                                                                                                // set by library:atmel-rf
#define MBED_CONF_ATMEL_RF_USE_SPI_SPACING_API                                0                                                                                                // set by library:atmel-rf
#define MBED_CONF_CELLULAR_DEBUG_AT                                           0                                                                                                // set by library:cellular
#define MBED_CONF_CELLULAR_RANDOM_MAX_START_DELAY                             0                                                                                                // set by library:cellular
#define MBED_CONF_CELLULAR_USE_APN_LOOKUP                                     1                                                                                                // set by library:cellular
#define MBED_CONF_DRIVERS_UART_SERIAL_RXBUF_SIZE                              256                                                                                              // set by library:drivers
#define MBED_CONF_DRIVERS_UART_SERIAL_TXBUF_SIZE                              256                                                                                              // set by library:drivers
#define MBED_CONF_ESP8266_DEBUG                                               0                                                                                                // set by library:esp8266
#define MBED_CONF_ESP8266_PROVIDE_DEFAULT                                     0                                                                                                // set by library:esp8266
#define MBED_CONF_ESP8266_SOCKET_BUFSIZE                                      8192                                                                                             // set by library:esp8266
#define MBED_CONF_EVENTS_PRESENT                                              1                                                                                                // set by library:events
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

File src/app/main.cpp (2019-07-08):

#include "Particle.h"

#include "serialDebug.h"
#include "ledStrip.h"
#include "cloudFunctions.h"
#include "statusLed.h"
#include "config.h"
#include "events.h"
#include "timers.h"

//run user code on boot to drive status LED
SYSTEM_MODE(SEMI_AUTOMATIC);

static const String LOG_MODULE = "MAIN";

static CloudFunctions *cloudFunctions;

int regFn(String name, int (CloudFunctions::*cloudFn)(String arg), CloudFunctions *cls) {
  return Particle.function(name, cloudFn, cls);
}

void setup() {
  statusLed::setup();
  ledStrip::setup();
  events::setup();
  timers::setup();

  cloudFunctions = new CloudFunctions(ledStrip::getDriver());
  cloudFunctions->registerFunctions(&regFn);

  Particle.connect();
}

/* Note: Code that blocks for too long (like more than 5 seconds), can make
 * weird things happen (like dropping the network connection).  The built-in
 * delay function shown below safely interleaves required background activity,
 * so arbitrarily long delays can safely be done if you need them.
 */
void loop() {
}

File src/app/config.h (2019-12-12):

#ifndef OBELISK_CONFIG_H
#define OBELISK_CONFIG_H

#define NUM_LEDS 18

#define TIMER_RESOLUTION_MS 25

#define PWM_DUTY_STEPS 10

/* #define COLOUR_ORDER_RGB */
#define COLOUR_ORDER_GRB
/* #define COLOUR_ORDER_RGBW */

#define PATTERN_TIMEOUT_MS 60*60*1000
#define WIND_PATTERN_TIMEOUT_MS 30000
#define GPIO_L1_BUTTON B5
#define GPIO_L2_BUTTON B4

#define DEFAULT_LOOP_PERIOD_MS 2000

/**********************************
 * Status LED
 *********************************/
#define PIN_STATUS_LED D3
#define TIMER_RESOLUTION_STATUS_LED_MS 100

#define STATUS_RAPID_FLASH_PERIOD_MS 200
#define STATUS_FLASH_PERIOD_MS 500
#define STATUS_SLOW_FLASH_PERIOD_MS 2000
#define STATUS_BLINK_PERIOD_MS 3000

/*********************************************************************************
 *  Calculated values
 ********************************************************************************/

#ifdef COLOUR_ORDER_GRB
  #define COLOURS_PER_LED 3
  #define INDEX_GREEN 0
  #define INDEX_RED 1
  #define INDEX_BLUE 2
#endif

#ifdef COLOUR_ORDER_RGB
  #define COLOURS_PER_LED 3
  #define INDEX_RED 0
  #define INDEX_GREEN 1
  #define INDEX_BLUE 2
#endif

#ifdef COLOUR_ORDER_RGBW
  #define COLOURS_PER_LED 4
  #define INDEX_RED 0
  #define INDEX_GREEN 1
  #define INDEX_BLUE 2
  #define INDEX_WHITE 3
#endif

#endif

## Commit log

2019-06-24 Added base code from Obelisk repo.
    [FA1.sch, FA1_BOM.xlsx, FA2.sch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]
2019-07-08 Added state reset and fade to new wind direction colour.
    [config.h, ledStrip.cpp]
2019-07-08 Restored status LED functionality (broken as part of RGBW work).
2019-07-09 Designed seeeduino mounting bracket for button enclosure.
    [assembly.scad, button_mount_plate.scad, constants.scad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]
2019-07-15 Started FP3 PCB layout.
    [FP3.kicad_pcb, FP3.sch]
2019-07-16 Finished FP3 sch and PCB, updated title blocks.
    [FA1.sch, FA2.sch, FP1.kicad_pcb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]
2019-07-16 Added test points and connector details for FP3.
    [FP3.kicad_pcb, FP3.sch]
2019-07-30 Added code for the seeeduino LoRa button.
2019-08-13 Added LoRa daughter board firmware (xDot).
2019-08-13 Added firmware for LoRa button (mDot based).
2019-09-03 Finalised mounting plate for LoRa button.
    [button_mount_plate.scad, constants.scad]
2020-01-09 Refactored toggle switch setup and handled initialisation of layer.
2020-01-13 Set 'defaultLoop' as pattern shown on power-up.
